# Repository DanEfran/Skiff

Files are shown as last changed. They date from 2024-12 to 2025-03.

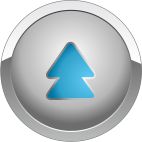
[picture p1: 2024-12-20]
references/EuroSynth - Signal Specification_files/pointer-up.jpg

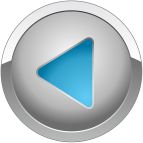
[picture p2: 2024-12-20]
references/EuroSynth - Signal Specification_files/pointer-left.jpg

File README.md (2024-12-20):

A small, never-finished Modular Synthesizer, emphasizing little 1u modules.

A "skiff" is a small-ish, often portable, modular synth rack -- compared to
the huge racks many folks covet. They are sometimes built into equipment
cases or the like, so they have latching lids and handles. Or a skiff might
just be a small-ish case, made of wood or whatever else suits the builder.

This skiff is presently a case made of foam core, though I consider that
a rough draft and expect to upgrade it to wood eventually. It has a pretty
standard DIY power supply (+12v/-12v) and a power distribution board with
some little connectors (not the big Eurorack standard ones, little servo-
style connectors with just the essential power lines) for the first batch
of modules. On the top edge are a power jack, power switch, and some MIDI
and audio jacks that aren't wired up yet. The rest is open space waiting
for small modules, which I'll build one at a time when I'm bored and have
free time between other projects. I expect this will take years and will
never be really finished, but hopefully the first few modules will make it
musically useful in some capacity.

The next step will be the output buffer/amplifier and a preliminary sound
source (possibly an arduino-powered module to jump-start the skiff).

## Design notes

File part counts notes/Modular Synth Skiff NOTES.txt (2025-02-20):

- Standards
	- Power input:
		- INPUT: 12VAC (AC: plug polarity irrelevant)
		- 2.1mm pin power jack:
			- Tayda SKU A-2237 "DC Power Jack 2.1mm Enclosed Frame With Switch"
		- current brick: Jameco ReliaPro 120VAC 60Hz 29 W -> 12VAC 2000mA
		- main power switch: 
			- Tayda SKU A-4727 "Yellow LED Dot Light Rocker Switch ON/OFF SPST 12V"
	- Module power connectors:
		- Tayda SKU A-5505 "3 Pins JST XH-2.54 Male connector Straight 180°"
		- Tayda SKU A-6682 "3 Pins JST XH-2.54 Female connector with Cable"
			- Black: GND. Red: +12v. Yellow: -12v.
		- Modules needing 5v, etc. must work it out for themselves.
	- Exterior dimensions
		- 12" wide 8.25" tall 55mm deep
		- Current version is foam core board; imperfect but approximately correct size
			to fit in vertical mounting space. Replace with a sturdier version any time.
	- Interior dimensions
		- about 4U x 56 HP x 45mm:
		- depth 45mm (back wall to back of faceplates, which sit about 5mm behind box edge)
			- depth of MIDI/MIXER is much less due to POWER behind them.
		- width 290-292mm (about ~11.5", slightly narrower at power supply end)
			- about 55-57 HP modular rack unit width, depending on tolerances
		- height 7" = 177-178mm
			- 4U modular rack unit height
			- plus 7/8" POWER/MIDI/MIXER strip, which is not counted in the rack size
				- which could be top or bottom! I've been thinking of it as the top,
					but it might be more ergonomic at the bottom, with the power cord
					and such hanging down below the box, when used vertically. If the
					skiff is used on a flat surface, it's probably more ergonomic at
					the top. It should be kept as reversible as possible.
		- faceplace sizes
			- Roughly based on existing 1U Tile standards:
			- Height per U is about 44mm, closest to Pulp Logic 1U height of 43.18mm
				- Intellijel 1U is 39.65mm high, which would leave gaps (for rail edges?)
			- Width of a 6HP tile: about 30mm
				- Pulp Logic uses 30.48mm; Intellijel 30mm
			- Holes diameter 3.175mm; centered 5.08mm from sides, 2.9972mm from top/bottom 
				- Following Pulp Logic's holes, farther from center than Intellijel
			- PCB clearance (for rails and neighbors)
				- Pulp Logic specifies a PCB maximum height of 28.702mm,
					width margin each side of 1.27mm (e.g. width 27.46 out of 30).
			- I might not be so precise about PCB size limits, but there isn't much room.
	- Signals
		- Audio
			- Line level? +/- 2.5v?
		- CV
			- 1v/Oct, 1 volt per octave
		- Gate
			- ?
	- Studio integration
		- InsertMe port can connect to Insert 3 on UMC-404HD, taking input from the
			microphone (low level, easily ignored) and sending output back to the
			studio in place of the microphone input (rarely used in my productions)
		- InsertMe port can connect instead to Insert 4 on UMC-404HD, to act as a
			guitar effects chain. Insert 4 is guitar, and the Skiff can use it as
			an input and return a processed version.
			- I believe the internal wiring of the UMC-404HD puts the front knob
				for each input between the input and the insert, so we can (for
				example) simply turn down the guitar input to switch from guitar
				effects mode to skiff-only mode. (For guitar-only, the skiff would
				need to pass the InsertMe input to its output cleanly. My design
				does not currently provide for that, so I expect to use the skiff
				primarily on Insert 4, replacing the microphone I rarely use, rather
				than as a guitar effects chain. I have VSTs for that, and the skiff
				isn't being designed with that in mind. It's simply a cool potential
				alternate mode that the InsertMe port allows for, to keep in mind.)
		- Headphone out can be used as a general-purpose stereo out (though "stereo"
			will likely be just the same signal in both ears).
		- MIDI IN allows external sequencers (etc.) to generate CV and gate outputs
			from "Module Zero", the top/bottom strip. In addition to the modular signals,
			we'll also generate an audio signal: the MIDI IN portion of Module Zero
			can be used as a mini-synth or MCO (MIDI-controlled oscillator). This is
			sort of cheating, but will be a valuable shortcut before I have more
			modules built. By starting with an MCO, I can immediately get in-tune
			waveforms to test the skiff's audio chain(s) with. Indeed, it will 
			immediately be a playable instrument, before any modules. At first there
			will be just one of each type of output (audio, CV, Gate), but it's probably 
			best to leave room on the front panel for several more. (Internally, they
			can be easily added later via a plug-in I2C/Stemma QT multi-DAC board.)

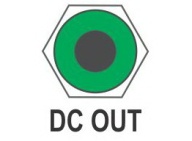
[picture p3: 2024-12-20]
references/EuroSynth - Signal Specification_files/jack-green.jpg

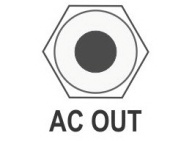
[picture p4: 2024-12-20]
references/EuroSynth - Signal Specification_files/jack-white.jpg

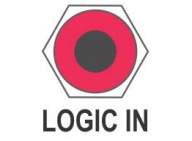
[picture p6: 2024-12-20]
references/EuroSynth - Signal Specification_files/jack-red.jpg

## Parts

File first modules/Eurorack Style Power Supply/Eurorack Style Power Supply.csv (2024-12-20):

Source: | D:\hacking\src\arduino\Modular Synth\first modules\Eurorack Style Power Supply\Eurorack Style Power Supply.kicad_sch
Date: | 4/28/2023 11:34
Tool: | Eeschema 7.0.1
Generator: | P:\programs\KiCad\7.0\bin\scripting\plugins/bom_csv_grouped_by_value.py
Component Count: | 25
Collated Components:
Item | Qty | Reference(s) | Value | LibPart | Footprint | Datasheet | DNP | Sim.Device | Sim.Pins
1 | 6 | C1, C2, C3, C6, C7, C8 | 3300uF | Device:C_Polarized | Capacitor_THT:CP_Axial_L30.0mm_D18.0mm_P35.00mm_Horizontal | ~
2 | 4 | C4, C5, C9, C10 | 1uF | Device:C_Polarized | Capacitor_THT:CP_Radial_Tantal_D4.5mm_P2.50mm | ~
3 | 6 | D1, D2, D3, D4, D5, D6 | 1N4004 | Diode:1N4004 | Diode_THT:D_DO-41_SOD81_P10.16mm_Horizontal | http://www.vishay.com/docs/88503/1n4001.pdf |  | D | 1=K 2=A
4 | 1 | J1 | Barrel_Jack | Connector:Barrel_Jack |  | ~
5 | 1 | J2 | Conn_01x04 | Connector_Generic:Conn_01x04 | Connector_PinHeader_2.54mm:PinHeader_1x04_P2.54mm_Vertical | ~
6 | 4 | J3, J4, J5, J6 | Conn_01x02 | Connector_Generic:Conn_01x02 | Connector_PinHeader_2.54mm:PinHeader_1x02_P2.54mm_Vertical | ~
7 | 1 | SW1 | SW_SPST | Switch:SW_SPST |  | ~
8 | 1 | U1 | LM7812_TO220 | Regulator_Linear:LM7812_TO220 | Package_TO_SOT_THT:TO-220-3_Vertical | https://www.onsemi.cn/PowerSolutions/document/MC7800-D.PDF
9 | 1 | U2 | LM7912_TO220 | Regulator_Linear:LM7912_TO220 | Package_TO_SOT_THT:TO-220-3_Vertical | hhttps://www.onsemi.com/pub/Collateral/MC7900-D.PDF

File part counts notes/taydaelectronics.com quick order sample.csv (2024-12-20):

sku | qty
MH01 | 2
24-WG080 | 1
24-WG085_Group | 4

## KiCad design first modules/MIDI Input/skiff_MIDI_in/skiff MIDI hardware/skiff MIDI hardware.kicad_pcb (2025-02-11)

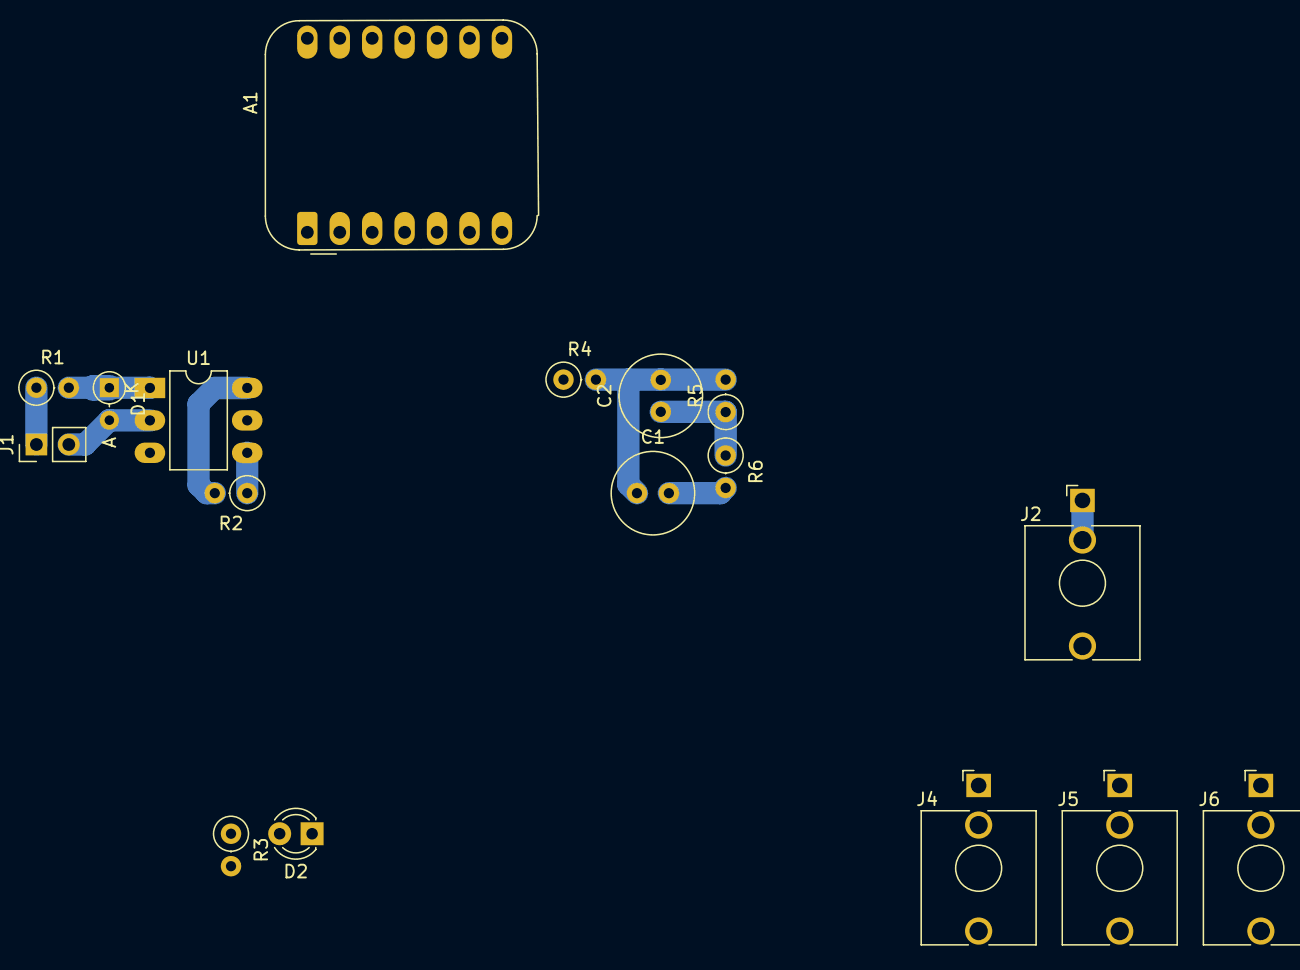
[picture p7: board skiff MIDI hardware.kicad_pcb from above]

Board: 2 copper layers, 17 parts (0 on the bottom side), 12 nets.

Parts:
A1: Adafruit_QT_PY_RP2040_DSE
C1: 47u; C_Radial_D6.3mm_H7.0mm_P2.50mm
C2: 100n; C_Radial_D6.3mm_H7.0mm_P2.50mm
D1: D; D_DO-34_SOD68_P2.54mm_Vertical_AnodeUp
D2: LED; LED_D3.0mm
J1: PinHeader_1x02_P2.54mm_Vertical
J2: Audio Out; Jack_3.5mm_QingPu_WQP-PJ398SM_Vertical_CircularHoles
J4: CV Out; Jack_3.5mm_QingPu_WQP-PJ398SM_Vertical_CircularHoles
J5: Gate Out; Jack_3.5mm_QingPu_WQP-PJ398SM_Vertical_CircularHoles
J6: Clock Out; Jack_3.5mm_QingPu_WQP-PJ398SM_Vertical_CircularHoles
R1, R4: 220; R_Axial_DIN0207_L6.3mm_D2.5mm_P2.54mm_Vertical
R2: 470; R_Axial_DIN0207_L6.3mm_D2.5mm_P2.54mm_Vertical
R3: 2k2; R_Axial_DIN0207_L6.3mm_D2.5mm_P2.54mm_Vertical
R5: 100; R_Axial_DIN0207_L6.3mm_D2.5mm_P2.54mm_Vertical
R6: 1k8; R_Axial_DIN0207_L6.3mm_D2.5mm_P2.54mm_Vertical
U1: H11L1; DIP-6_W7.62mm_LongPads

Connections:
+3V3: A1.12 (3V3), R2.2, R3.2, U1.6
A0: A1.1 (A0), D2.1 (K), R2.1, U1.4
GND: A1.13 (GND), C2.1, J2.R, J2.S, R5.1, R6.1, U1.5
unnamed: A1.2 (A1), J6.T
unnamed: A1.8 (RX), J5.T
unnamed: C1.1, C2.2, R4.2, R5.2
unnamed: C1.2, J2.T, R6.2
unnamed: D1.2 (A), J1.2, U1.2
unnamed: D1.1 (K), R1.2, U1.1
unnamed: D2.2 (A), R3.1
unnamed: J1.1, R1.1
TX: A1.7 (TX), R4.1

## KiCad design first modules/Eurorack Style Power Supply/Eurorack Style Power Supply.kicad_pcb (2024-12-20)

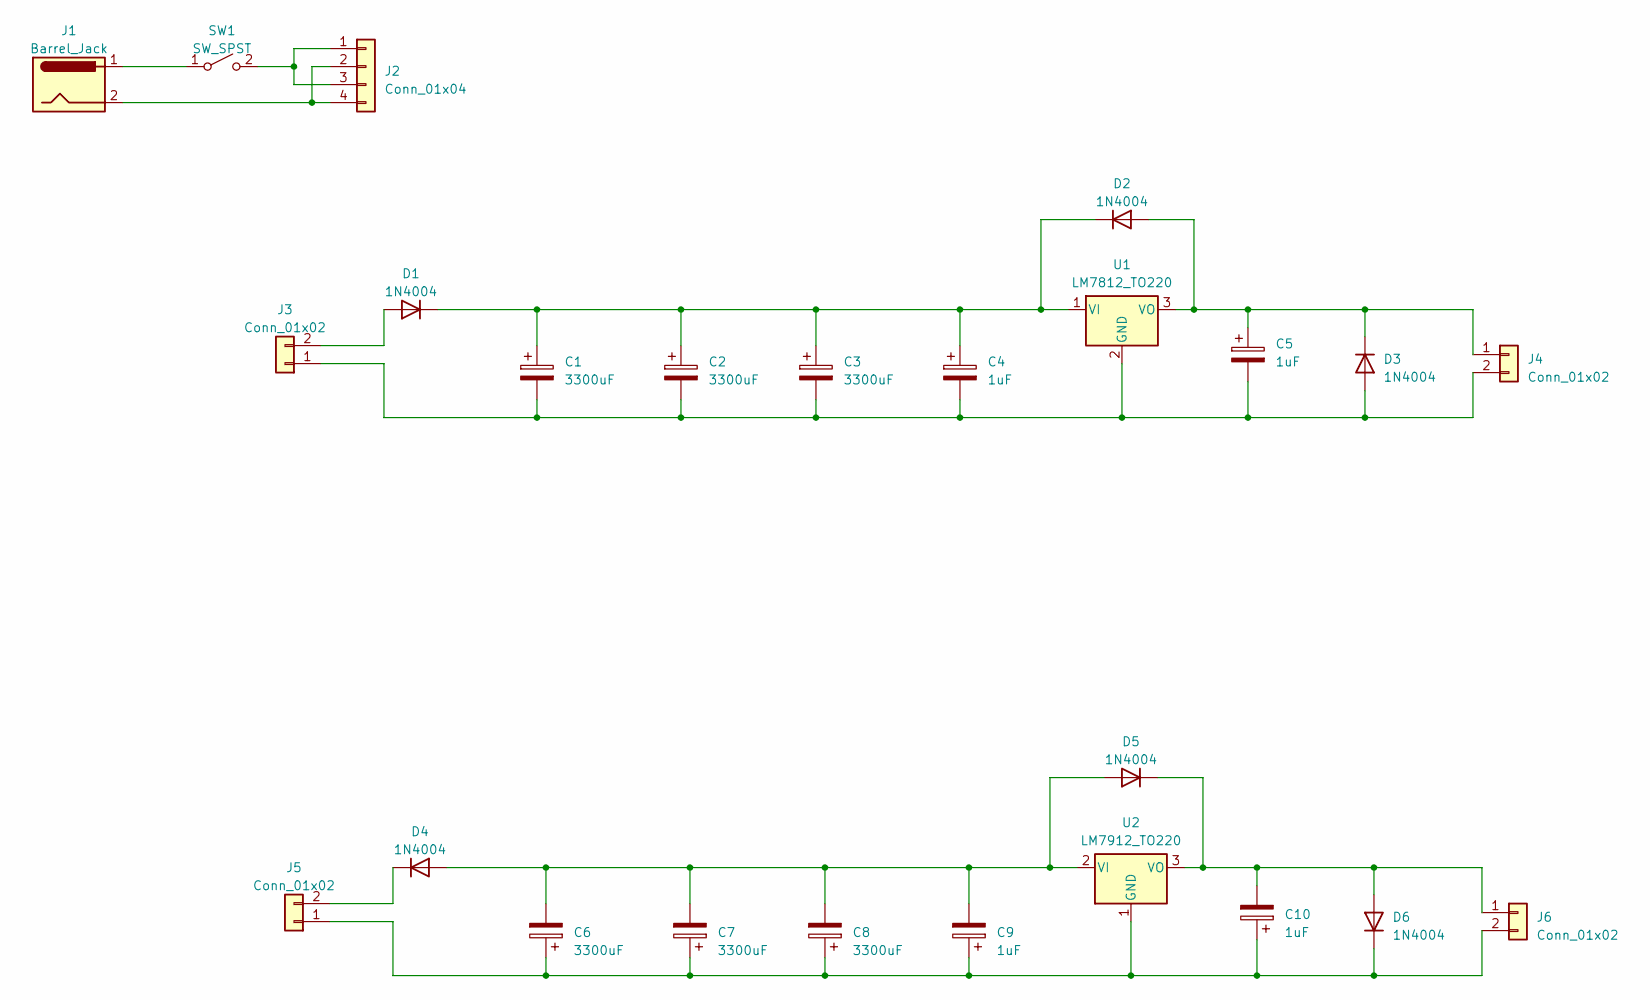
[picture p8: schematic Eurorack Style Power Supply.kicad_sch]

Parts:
C1, C2, C3, C6, C7, C8: 3300uF; CP_Axial_L30.0mm_D18.0mm_P35.00mm_Horizontal
C4, C5, C9, C10: 1uF; CP_Radial_Tantal_D4.5mm_P2.50mm
D1, D2, D3, D4, D5, D6: 1N4004; D_DO-41_SOD81_P10.16mm_Horizontal
J1: Barrel_Jack; BarrelJack_CUI_PJ-063AH_Horizontal_CircularHoles
J2: Conn_01x04; PinHeader_1x04_P2.54mm_Vertical
J3, J4, J5, J6: Conn_01x02; PinHeader_1x02_P2.54mm_Vertical
SW1: SW_SPST; SW_Lever_1P2T_NKK_GW12LxH
U1: LM7812_TO220; TO-220-3_Vertical
U2: LM7912_TO220; TO-220-3_Vertical

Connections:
unnamed: D1.2 (A), J3.2
unnamed: C1.1, C2.1, C3.1, C4.1, D1.1 (K), D2.1 (K), U1.1 (VI)
unnamed: C5.1, D2.2 (A), D3.1 (K), J4.1, U1.3 (VO)
unnamed: C1.2, C2.2, C3.2, C4.2, C5.2, D3.2 (A), J3.1, J4.2, U1.2 (GND)
unnamed: C6.2, C7.2, C8.2, C9.2, D4.2 (A), D5.2 (A), U2.2 (VI)
unnamed: D4.1 (K), J5.2
unnamed: C10.2, D5.1 (K), D6.2 (A), J6.1, U2.3 (VO)
unnamed: C6.1, C7.1, C8.1, C9.1, C10.1, D6.1 (K), J5.1, J6.2, U2.1 (GND)
unnamed: J2.1, J2.3, SW1.2 (B)
unnamed: J1.2, J2.2, J2.4
unnamed: J1.1, SW1.1 (A)

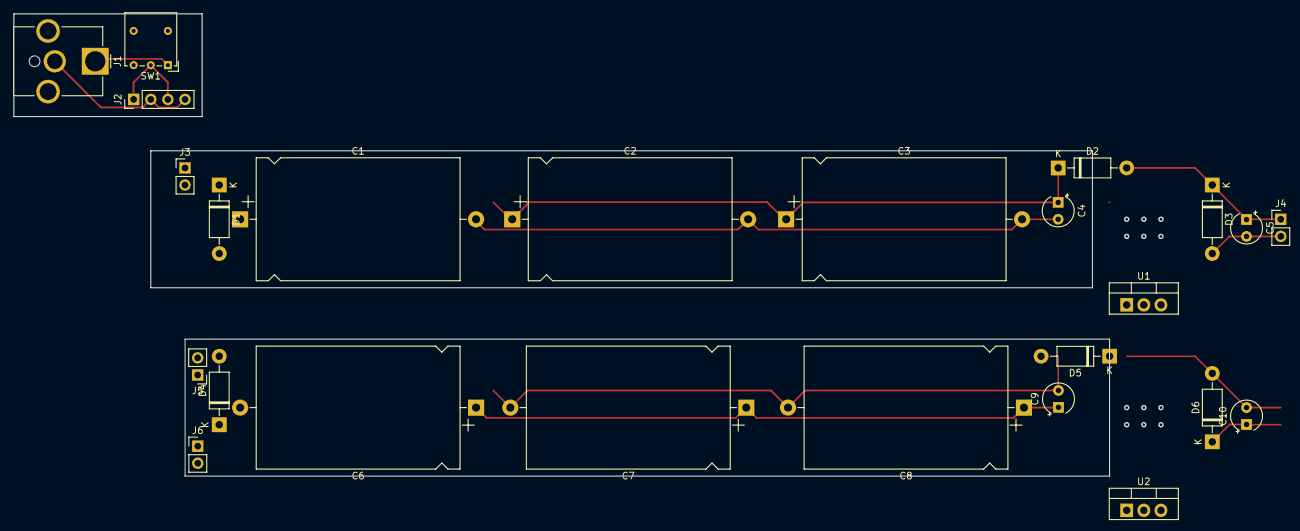
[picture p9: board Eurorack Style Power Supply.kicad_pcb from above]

Board: 2 copper layers, 162.6 x 68.6 mm, 25 parts (0 on the bottom side), 11 nets.

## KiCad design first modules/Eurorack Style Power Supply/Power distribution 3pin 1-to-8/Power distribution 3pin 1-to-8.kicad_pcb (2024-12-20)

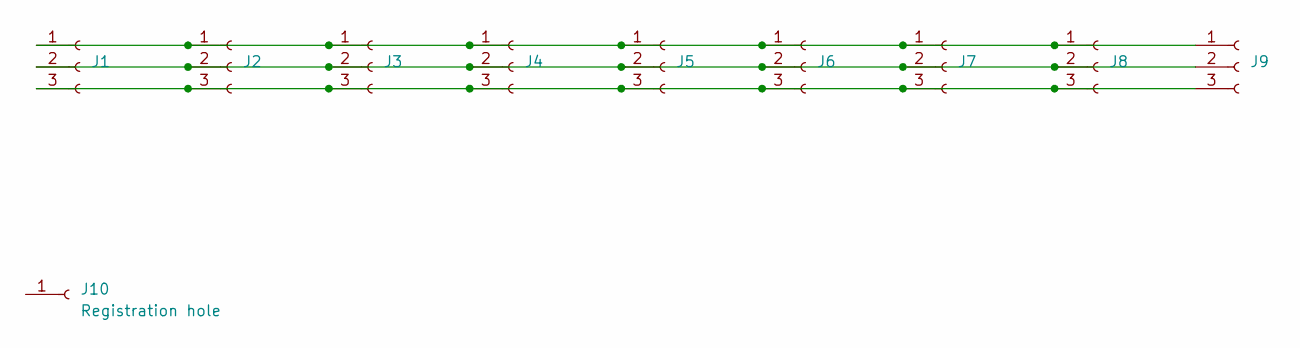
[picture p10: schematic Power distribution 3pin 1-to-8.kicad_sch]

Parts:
J1, J2, J3, J4, J5, J6, J7, J8, J9: Conn_01x03_Socket; PinHeader_1x03_P2.54mm_Vertical
J10: Registration hole; PinHeader_1x01_P2.54mm_Vertical

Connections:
unnamed: J1.1, J2.1, J3.1, J4.1, J5.1, J6.1, J7.1, J8.1, J9.1
unnamed: J1.2, J2.2, J3.2, J4.2, J5.2, J6.2, J7.2, J8.2, J9.2
unnamed: J1.3, J2.3, J3.3, J4.3, J5.3, J6.3, J7.3, J8.3, J9.3
registration: J10.1

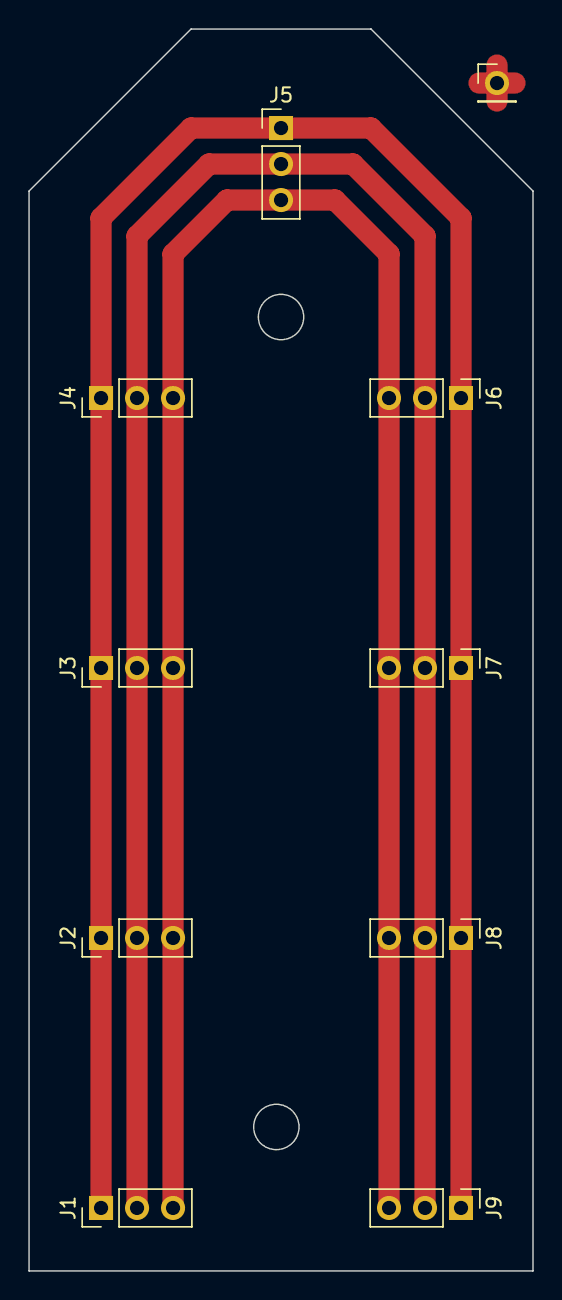
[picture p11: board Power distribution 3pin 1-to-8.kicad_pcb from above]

Board: 2 copper layers, 35.6 x 87.6 mm, 10 parts (0 on the bottom side), 3 nets.

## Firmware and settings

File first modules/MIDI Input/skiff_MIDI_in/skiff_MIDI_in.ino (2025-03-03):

// skiff_MIDI_in.ino
// firmware for a small MIDI IN module for a modular synthesizer
// Dan Efran 2025
//
// Hardware:
// - Adafruit QT Py RP2040 
//    - https://www.adafruit.com/product/4900
//    - 3.3v
// - Adafruit MCP4728 Breakout Board 
//    https://www.adafruit.com/product/4470
//    - MCP4728 4-Channel 12-bit I2C DAC - STEMMA QT
// - 0.96" 80x160 RGB IPS display
//    - SPI interface
//    - breakout board carved down by about 5mm to fit in a smaller space
// - Rotary encoder with push switch
// - Toggle switch; DIN-5 MIDI jack; 1/4" stereo TRS jack; 1/8" mono jacks 

/*
    NOTES
    - DAC board is not responding. I may have damaged it when soldering
      and desoldering? It's got a huge heat sinking ground plane,
      apparently, so the '-' output pad is almost unsolderable.
      The Stemma QT port seems to work with other i2c boards, so I'll
      have to try another DAC board. [2025-03-03]
    - Switching to backup DAC, MCP4728: 4 channels but a lower bit depth;
      for 1v/oct it shouldn't matter - I can always restrict each voice
      to a range if the linearity is too rough for a full range. 
      This board works, and this way I get a MIDI quartet. [2025-03-03]
    - Hardware is otherwise in good shape, but each output needs some
      kind of buffering: the audio is probably close to an acceptable
      level (?) but should probably be buffered; the Gate output 
      should probably be raised to 5 or 10 v; the DAC output (when I
      have one that works) will probably need to be doubled or even
      tripled to give a decent octave range; that will count as a
      buffer as well. Then the speaker will need a small amplifier,
      with a volume attenuator knob. 
*/

#include "display.h"
#include "neopixel.h"
#include "SimpleSynth.h"
#include "rotary.h"
#include "DAC.h"

time_t initSerial() {

  Serial.begin(115200);
  while (!Serial && (millis() < 10000));
  return millis();

}

void setup(void) {
  
  time_t serial_startup_time = initSerial();

  Serial.print(F("Hello! Serial connect time:"));
  Serial.println(serial_startup_time);


  initNeopixel();
  initDisplay();
  initSimpleSynth();
  initRotary();
  initDAC();

  Serial.println(F("Subsystems initialized"));
  
  testClearScreen();
  testroundrects();

  Serial.println("Skiff MIDI In: ready.");

}

void loop() {
  
  loopSimpleSynth();
  loopDACTest();

}

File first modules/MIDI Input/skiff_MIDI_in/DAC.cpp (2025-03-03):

// DAC.cpp
// skiff_MIDI_in

#include "DAC.h"

// Demo for configuring the Vref of the MCP4728 4-Channel 12-bit I2C DAC
#include <Adafruit_MCP4728.h>
#include <Wire.h>

Adafruit_MCP4728 mcp;

void initDAC(void) {
  
  Serial.println("Adafruit MCP4728 test!");

  // Try to initialize!
  if (!mcp.begin(MCP4728_I2CADDR_DEFAULT, &Wire1)) {
    Serial.println("Failed to find MCP4728 chip");
    return;
  }
  Serial.println("MCP4728 Found!");
  /*
   * @param channel The channel to update
   * @param new_value The new value to assign
   * @param new_vref Optional vref setting - Defaults to `MCP4728_VREF_VDD`
   * @param new_gain Optional gain setting - Defaults to `MCP4728_GAIN_1X`
   * @param new_pd_mode Optional power down mode setting - Defaults to
   * `MCP4728_PD_MOOE_NORMAL`
   * @param udac Optional UDAC setting - Defaults to `false`, latching (nearly).
   * Set to `true` to latch when the UDAC pin is pulled low
   *
   */

  // we've saved the configuration below to the EEPROM at least once;
  // do we need to do it again? theoretically not?
  bool already_saved = true;

  if (!already_saved) {

    // configure for internal voltage reference within 3v3 supply range
    // nominally 2.048v

    // I'm getting readings that don't look like 2.048v in early tests;
    // needs more testing. (Exact voltage isn't important but stability is.)

    // also, start with outputs at 0

    mcp.setChannelValue(MCP4728_CHANNEL_A, 0, MCP4728_VREF_INTERNAL,
                        MCP4728_GAIN_1X);
    mcp.setChannelValue(MCP4728_CHANNEL_B, 0, MCP4728_VREF_INTERNAL,
                        MCP4728_GAIN_1X);
    mcp.setChannelValue(MCP4728_CHANNEL_C, 0, MCP4728_VREF_INTERNAL,
                        MCP4728_GAIN_1X);
    mcp.setChannelValue(MCP4728_CHANNEL_D, 0, MCP4728_VREF_INTERNAL,
                        MCP4728_GAIN_1X);

    mcp.saveToEEPROM();
  }

  // is initial value among the EEPROM-saved settings? If not:
  // mcp.setChannelValue(MCP4728_CHANNEL_B, 0);
  // mcp.setChannelValue(MCP4728_CHANNEL_C, 0);
  // mcp.setChannelValue(MCP4728_CHANNEL_D, 0);
  // mcp.setChannelValue(MCP4728_CHANNEL_A, 0);

}

void loopDACTest() {
  
  // quick and dirty test

  static int which = 0;
  static int when = 0;

  if (++when % 100000) {
    return;
  }

  which = (which + 1) % 4;

  switch (which) {

    case 0:
      mcp.setChannelValue(MCP4728_CHANNEL_B, 4095);
      mcp.setChannelValue(MCP4728_CHANNEL_C, 2048);
      mcp.setChannelValue(MCP4728_CHANNEL_D, 1024);
      mcp.setChannelValue(MCP4728_CHANNEL_A, 0);
      break;

    case 1:
      mcp.setChannelValue(MCP4728_CHANNEL_C, 4095);
      mcp.setChannelValue(MCP4728_CHANNEL_D, 2048);
      mcp.setChannelValue(MCP4728_CHANNEL_A, 1024);
      mcp.setChannelValue(MCP4728_CHANNEL_B, 0);
      break;

    case 2:
      mcp.setChannelValue(MCP4728_CHANNEL_D, 4095);
      mcp.setChannelValue(MCP4728_CHANNEL_A, 2048);
      mcp.setChannelValue(MCP4728_CHANNEL_B, 1024);
      mcp.setChannelValue(MCP4728_CHANNEL_C, 0);
      break;

    case 3:
      mcp.setChannelValue(MCP4728_CHANNEL_A, 4095);
      mcp.setChannelValue(MCP4728_CHANNEL_B, 2048);
      mcp.setChannelValue(MCP4728_CHANNEL_C, 1024);
      mcp.setChannelValue(MCP4728_CHANNEL_D, 0);
      break;
  }

}

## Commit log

2024-12-20 Initial git commit of progress so far: Power Supply board is done; Power distribution board is done; the foam-core first draft skiff case is done; the top panel with power switch etc. is done, at lea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
    [Eurorack Style Power Supply.csv, Eurorack Style Power Supply.kicad_pcb, Eurorack Style Power Supply.kicad_sch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]
2025-02-11 MIDI In: schematic & PCB: several subsections
    [skiff MIDI hardware.kicad_pcb, skiff MIDI hardware.kicad_sch]
2025-02-11 PCB in progress; Schematic lacks only output stages (Outputs don't yet conform to Modular Synth signal standards, but schematic should be otherwise ok.)
    [skiff MIDI hardware.kicad_pcb, skiff MIDI hardware.kicad_sch]
2025-02-11 Main arduino sketch file: just example code so far (checking that the display works; MIDI test is in a separate sketch, soon to be added to this one)
2025-02-11 Minor changes to files. New KiCad version
2025-02-11 Sch: Add Rotary Encoder; move DAC to Stemma QT i2c; Remove Clock output (it was an optional bonus, but there's no pin available for it. I suppose we could chain additional outputs onto the Stemma QT 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
    [skiff MIDI hardware.kicad_sch]
2025-03-01 Schematic: add power switch. minor cleanup.
    [skiff MIDI hardware.kicad_sch]
2025-03-02 Add SimpleSynth example code in its own file(s). MILESTONE: MIDI input produces basic Audio and Gate outputs, and display is working (though not showing anything of interest yet). CV output is not ye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
2025-03-03 Rotary encoder: simple test in rotary.cpp/.h
2025-03-03 Rotary encoder: monitored via interrupts. Proof-of-concept only: Serial printing inside the interrupt handlers; knob badly needs debouncing. So these are not the real interrupt handlers, but the wiri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
2025-03-03 New DAC board: simple test in DAC.cpp/.h; it works. Voltage in early tests doesn't seem to match the nominal/expected reference; test more. But any consistent voltage will work. Now this module just 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
    [DAC.cpp, skiff_MIDI_in.ino]
